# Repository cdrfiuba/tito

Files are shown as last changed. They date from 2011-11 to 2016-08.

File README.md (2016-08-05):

Project created on: 2011-04-29 21:04:24
Project last updated on: 2013-04-11 14:27:10
Project members:
 Martín Mello Teggia <martinmt139@gmail.com>
 Damián Cudero <misael.k@gmail.com>
 anonimo anonimo <nin@guno.com>
 Gisela Farace <gisela.farace@gmail.com>
 Gustavo Crescentini <guscres@gmail.com>

TITO el autito más bonito.

[Descargar copia del repositorio](https://labi.fi.uba.ar/codigo/tito/archive/tip.zip)

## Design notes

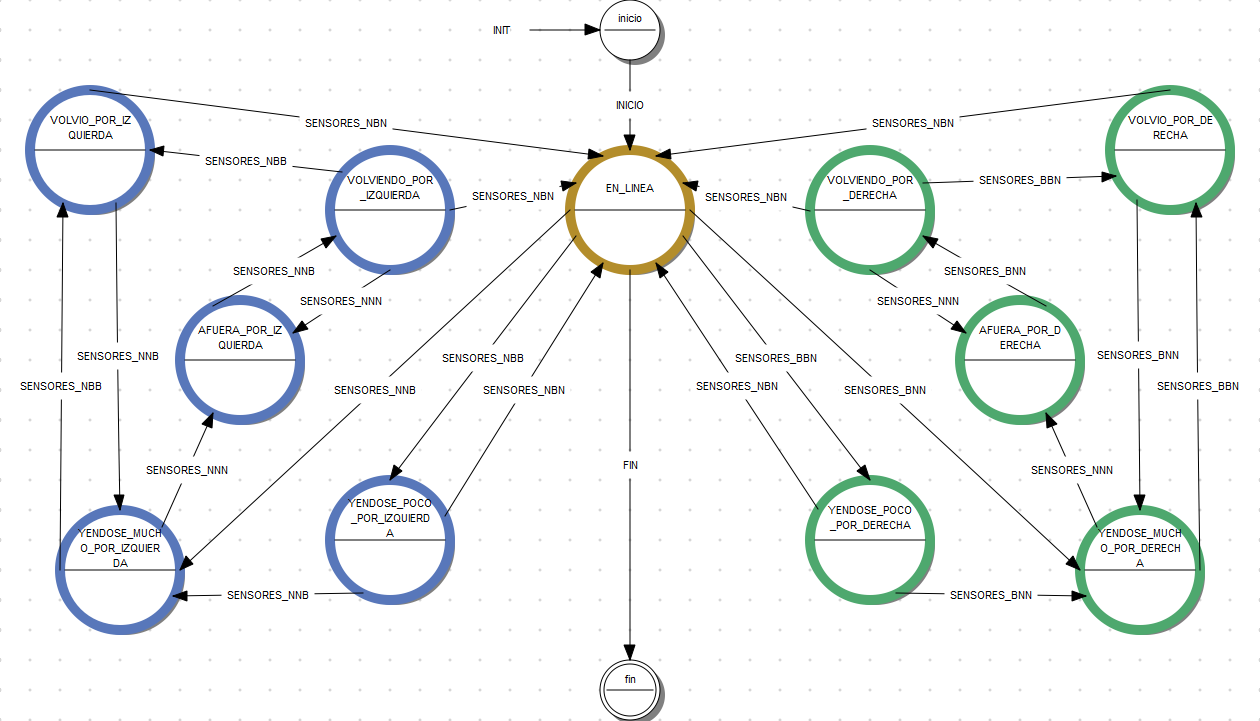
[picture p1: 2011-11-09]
Otros/Maquina de estados.png

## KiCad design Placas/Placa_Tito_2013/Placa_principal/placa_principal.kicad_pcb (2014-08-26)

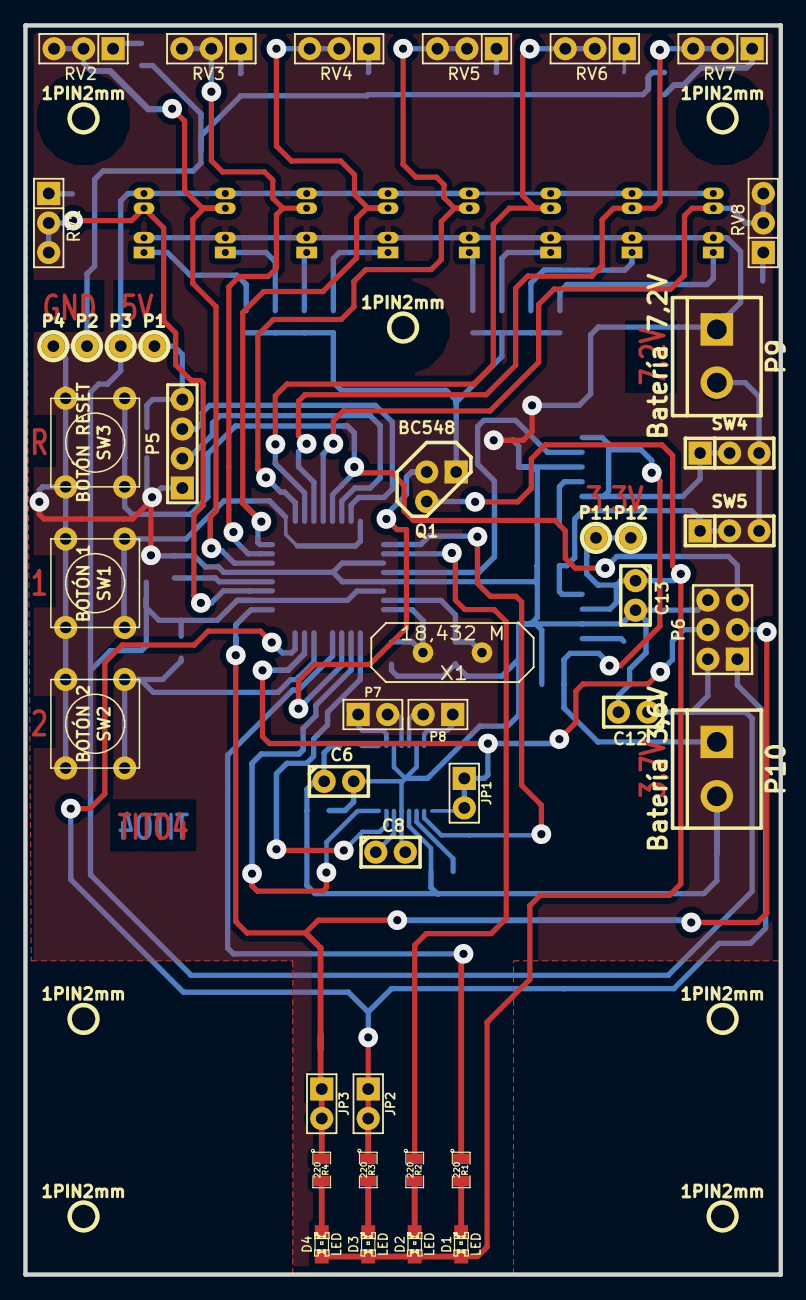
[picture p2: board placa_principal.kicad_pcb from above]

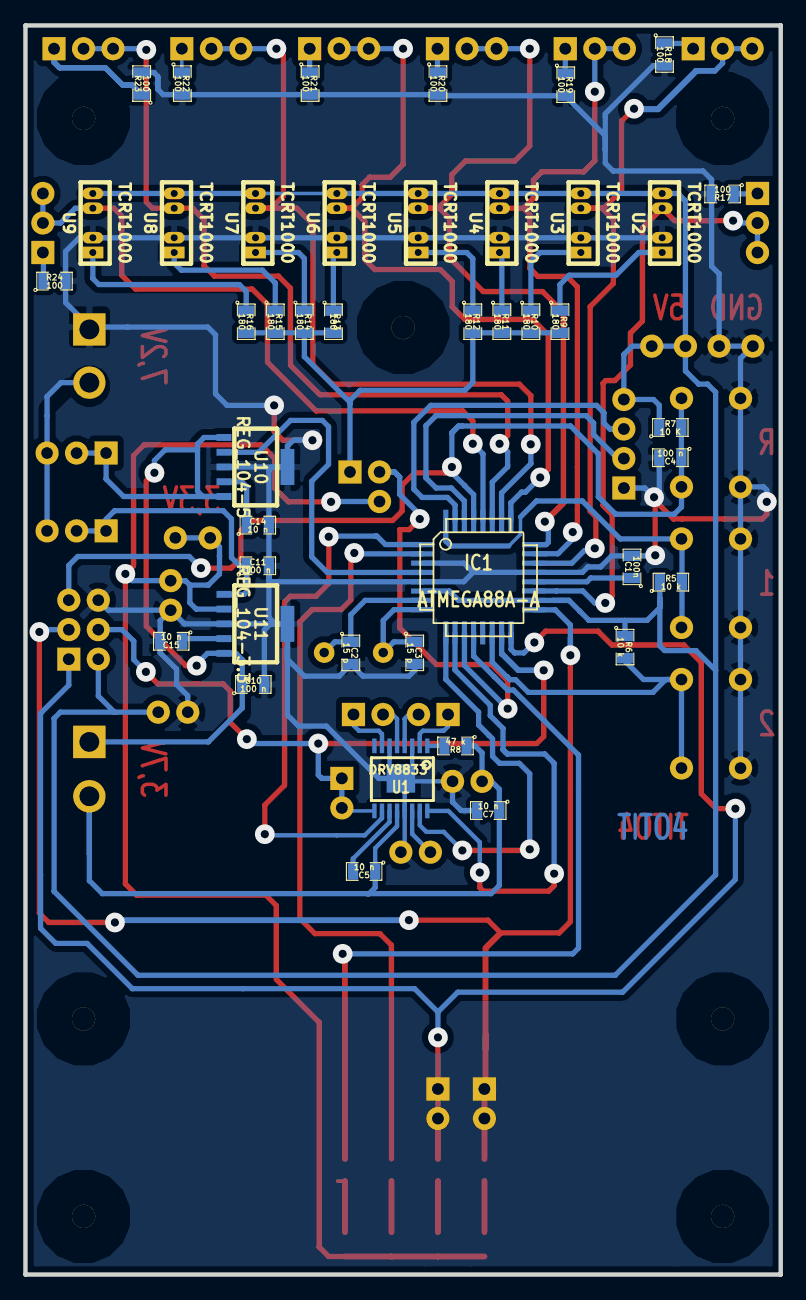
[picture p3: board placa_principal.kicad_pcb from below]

Board: 2 copper layers, 65.0 x 107.5 mm, 91 parts (42 on the bottom side), 65 nets.

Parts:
1PIN2mm, 1PIN2mm#2, 1PIN2mm#3, 1PIN2mm#4, 1PIN2mm#5, 1PIN2mm#6, 1PIN2mm#7: P***; 1PIN2mm
C1: 100n; SM0805
C2, C3: 15 p; SM0805
C4, C10, C11: 100 n; SM0805
C5, C7, C14, C15: 10 n; SM0805
C6: 2200 u; C1
C8: 2,2 u; C1
C12, C13: 220 u; C1
D1, D2, D3, D4: LED; LED-0805
IC1: ATMEGA88A-A; TQFP32
JP1, JP2, JP3: PUENTE FALLBACK; PIN_ARRAY_2X1
P1, P3: ADICIONAL 5V; 1PIN2mm
P2, P4: ADICIONAL GND; 1PIN2mm
P5: Puerto Serie; PIN_ARRAY_4x1
P6: Programador; pin_array_3x2
P7: Motor 1; PIN_ARRAY_2X1
P8: Motor 2; PIN_ARRAY_2X1
P9: Batería 7,2V; bornier2
P10: Batería 3,6V; bornier2
P11, P12: ADICIONAL 3,3V; 1PIN2mm
Q1: BC548; TO92-123
R1, R2, R3, R4: 220; SM0805
R5, R6: 10 k; SM0805
R7: 10 K; SM0805
R8: 47 k; SM0805
R9, R10, R11, R12, R13, R14, R15, R16: 180; SM0805
R17, R18, R19, R20, R21, R22, R23, R24: 100; SM0805
RV1, RV2, RV3, RV4, RV5, RV6, RV7, RV8: POT 20 k; PIN_ARRAY_3X1
SW1: BOTÓN 1; SW_PUSH_SMALL
SW2: BOTÓN 2; SW_PUSH_SMALL
SW3: BOTÓN RESET; SW_PUSH_SMALL
SW4: INTERRUPTOR BATERÍA 7,2V; MICROSWITCH_SPST
SW5: INTERRUPTOR REGULADOR 3,3V; MICROSWITCH_SPST
U1: DRV8833; HTSSOP16
U2, U3, U4, U5, U6, U7, U8, U9: TCRT1000
U10: REG_104-5; SOT223-5
U11: REG_104-3.3; SOT223-5
X1: 18,432 M; HC-18UV

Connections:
+3.3V: C13.1, D1.1, D2.1, D3.1, D4.1, P11.1, P12.1, Q1.1, U11.2
+5V: C12.1, IC1.4, IC1.6, IC1.18, P1.1, P3.1, P5.4, P6.2, R5.1, R6.1, R7.1, U2.4, U3.4, U4.4, U5.4, U6.4, U7.4, U8.4, U9.4, U10.2
+BATT: C5.1, C6.1, C7.1, P10.2, R8.1, U1.12
/BOTÓN 1: IC1.32, R5.2, SW1.1
/BOTÓN 2: IC1.14, R6.2, SW2.1
/Control Motores/MOTOR A SALIDA 1: P7.1, U1.2
/Control Motores/MOTOR A SALIDA 2: P7.2, U1.4
/Control Motores/MOTOR B SALIDA 1: P8.1, U1.7
/Control Motores/MOTOR B SALIDA 2: P8.2, U1.5
/Control Motores/Motor A Entrada 1: IC1.10, U1.16
/Control Motores/Motor A Entrada 2: IC1.9, U1.15
/Control Motores/Motor B Entrada 1: JP1.2, U1.9
/Control Motores/Motor B Entrada 2: IC1.1, U1.10
/LED1: IC1.12, R1.1
/LED2: IC1.2, R2.1
/LED3: JP2.2, R3.1
/LED4: JP3.2, R4.1
/MISO: IC1.16, JP2.1, P6.1
/MOSI: IC1.15, JP1.1, P6.4
/PIN HABILITADOR: IC1.11, Q1.2
/RESET: C4.1, IC1.29, P6.5, R7.2, SW3.1
/RX: IC1.30, P5.2
/SCK: IC1.17, JP3.1, P6.3
/Sensores/Habilitador sensores: Q1.3, R9.2, R10.2, R11.2, R12.2, R13.2, R14.2, R15.2, R16.2
/Sensores/Sensor 1: IC1.19, RV1.2, RV1.3, U2.3
/Sensores/Sensor 2: IC1.22, RV2.2, RV2.3, U3.3
/Sensores/Sensor 3: IC1.23, RV3.2, RV3.3, U4.3
/Sensores/Sensor 4: IC1.24, RV4.2, RV4.3, U5.3
/Sensores/Sensor 5: IC1.25, RV5.2, RV5.3, U6.3
/Sensores/Sensor 6: IC1.26, RV6.2, RV6.3, U7.3
/Sensores/Sensor 7: IC1.27, RV7.2, RV7.3, U8.3
/Sensores/Sensor 8: IC1.28, RV8.2, RV8.3, U9.3
/TX: IC1.31, P5.3
/Xtal1: C2.1, IC1.7, X1.1
/Xtal2: C3.1, IC1.8, X1.2
GND: C1.2, C2.2, C3.2, C4.2, C6.2, C7.2, C8.2, C10.2, C11.2, C12.2, C13.2, C14.2, C15.2, IC1.3, IC1.5, IC1.21, P2.1, P4.1, P5.1, P6.6, P9.1, R17.2, R18.2, R19.2, R20.2, R21.2, R22.2, R23.2, R24.2, SW1.2, SW2.2, SW3.2, U1.3, U1.6, U1.13, U2.2, U3.2, U4.2, U5.2, U6.2, U7.2, U8.2, U9.2, U10.3, U11.3
unnamed: C1.1, IC1.20
unnamed: D3.2, R3.2
unnamed: D4.2, R4.2
unnamed: D1.2, R1.2
unnamed: D2.2, R2.2
unnamed: C11.1, SW5.1, SW5.2, U11.1
unnamed: C10.1, P10.1, SW4.1, SW4.2, U10.1, U10.5, U11.5
unnamed: C14.1, U10.4
unnamed: C15.1, U11.4
unnamed: R8.2, U1.1
unnamed: C5.2, U1.11
unnamed: C8.1, U1.14
unnamed: R14.1, U7.1
unnamed: R13.1, U6.1
unnamed: R15.1, U8.1
unnamed: R11.1, U4.1
unnamed: R22.1, RV6.1
unnamed: R17.1, RV1.1
unnamed: R18.1, RV2.1
unnamed: R19.1, RV3.1
unnamed: R10.1, U3.1
unnamed: R9.1, U2.1
unnamed: R21.1, RV5.1
unnamed: R24.1, RV8.1
unnamed: R23.1, RV7.1
unnamed: R16.1, U9.1
unnamed: R12.1, U5.1
unnamed: R20.1, RV4.1
VDD: P9.2, SW4.3, SW5.3

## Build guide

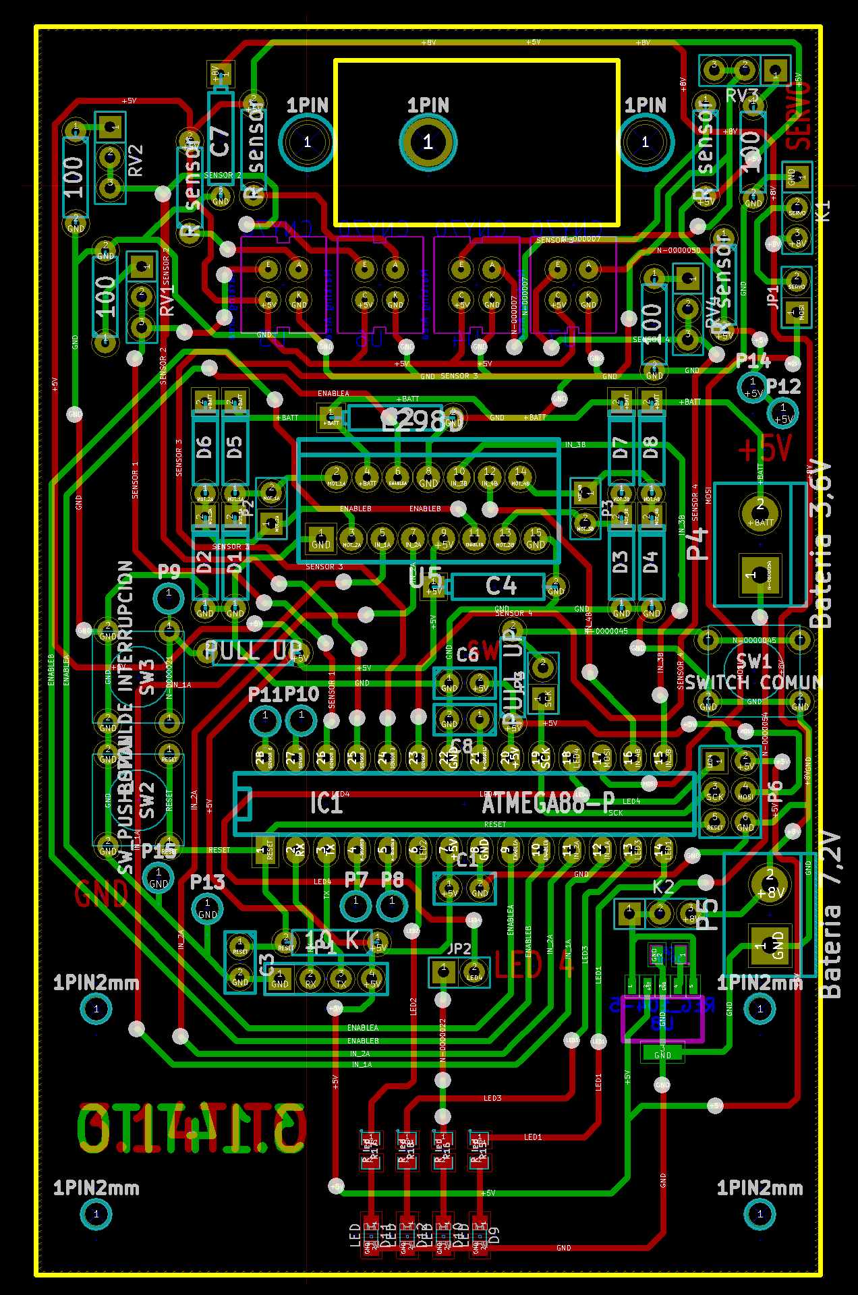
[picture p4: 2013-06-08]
Placas/Placa_Tito_2013/Placa_principal/Archivos de fabricacion/2013/Pantallazo.png

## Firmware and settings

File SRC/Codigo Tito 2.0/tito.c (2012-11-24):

#include <avr/io.h>
#include <avr/interrupt.h>
#define F_CPU 8000000UL
#include <util/delay.h>
#include "tito.h"
#include "lib/lib_pwm.h"
#include <avr/pgmspace.h>

void (*funciones[ST_MAX_ESTADOS])();

volatile uint16_t boost_en_linea_contador;
volatile int boost_en_linea;

void startup () {
// setear puertos de lectura o escritura,
// según corresponda

    // leds
    SetBit (DDR_LED_1, LED_1_NUMBER);
    SetBit (DDR_LED_2, LED_2_NUMBER);
    SetBit (DDR_LED_3, LED_3_NUMBER);
    SetBit (DDR_LED_4, LED_4_NUMBER);

    // sensores
    ClearBit (DDR_SENSOR_1, SENSOR_1_NUMBER);
    ClearBit (DDR_SENSOR_2, SENSOR_2_NUMBER);
    ClearBit (DDR_SENSOR_3, SENSOR_3_NUMBER);
    ClearBit (DDR_SENSOR_CURVA, SENSOR_CURVA_NUMBER);

    // botón
    ClearBit (DDR_BOTON, BOTON_NUMBER);
    SetBit (PORT_BOTON, BOTON_NUMBER);


    // PWM
    pwm_config();
    pwm_start();

    // pone el flag global para activar interrupciones
    sei();

    // establezco la dirección de los motores
    mot1_sent(AD);
    mot2_sent(AD);

}

/*Tabla de Posibles transiciones*/
static const int transiciones[ST_MAX_ESTADOS][EV_MAX_SENSORES] PROGMEM = {
                              /*NNNN NNNB NNBN NNBB NBNN NBNB NBBN NBBB BNNN BNNB BNBN BNBB BBNN BBNB BBBN BBBB*/
/* En Linea*/                   { ME,YMPI,YPPI,YMPI,YPPD,  ME,  ME,  ME,YMPD,  ME,  ME,  ME,YMPD,  ME,  ME,  ME}, 

/* Yendose Poco por Derecha*/   {APD,  ME,  EL,  ME,  ME,  ME,  EL,  ME,YMPD,  ME,  ME,  ME,YMPD,  ME,  ME,  ME}, 
/* Yendose Mucho por Derecha*/  {APD,VOPD,VOPD,VOPD,  EL,  ME,VOPD,  ME,  ME,  ME,  ME,  ME,  ME,  ME,  ME,  ME},
/* Afuera por Derecha*/         { ME,  ME,  ME,  ME,  ME,  ME,  ME,  ME,VEPD,  ME,  ME,  ME,VEPD,  ME,  ME,  ME}, 
/* Volviendo por Derecha*/      {APD,  ME,VOPD,  ME,  EL,  ME,  EL,  ME,  ME,  ME,  ME,  ME,  ME,  ME,  ME,  ME}, 
/* Volvio por Derecha*/         { ME,  ME,  EL,  ME,  EL,  ME,  EL,  ME,  ME,  ME,  ME,  ME,YPPD,  ME,  ME,  ME}, 

/* Yendose Poco por Izquierda*/ {API,YMPI,  ME,YMPI,  EL,  ME,  EL,  ME,  ME,  ME,  ME,  ME,  ME,  ME,  ME,  ME},
/* Yendose Mucho por Izquierda*/{API,  ME,  EL,  ME,VOPI,  ME,VOPI,  ME,VOPI,  ME,  ME,  ME,VOPI,  ME,  ME,  ME}, 
/* Afuera por Izquierda*/       { ME,VEPI,  ME,VEPI,  ME,  ME,  ME,  ME,  ME,  ME,  ME,  ME,  ME,  ME,  ME,  ME}, 
/* Volviendo por Izquierda*/    {API,  ME,  EL,  ME,VOPI,  ME,  EL,  ME,  ME,  ME,  ME,  ME,  ME,  ME,  ME,  ME}, 
/* Volvio por Izquierda*/       { ME,  ME,  EL,YPPI,  EL,  ME,  EL,  ME,  ME,  ME,  ME,  ME,  ME,  ME,  ME,  ME}  
};


void st_en_linea () {
    PWM1_VEL(COEFICIENTE_IZQUIERDA * (60 + 0));
    PWM2_VEL(COEFICIENTE_DERECHA   * (60 + 0));
    mot1_sent(AD);
    mot2_sent(AD);
};

void st_yendose_poco_por_derecha () {
	//USAR_FRENOS(250, 250);
    #ifdef ACTIVAR_PROPULSORES_TRASEROS
        PWM1_VEL(1.4 * COEFICIENTE_IZQUIERDA * 100);
        PWM2_VEL(1.4 * COEFICIENTE_DERECHA  *  50);
        mot1_sent(AD);
        mot2_sent(AT);
        _delay_ms (1);
    #endif
          
    PWM1_VEL(COEFICIENTE_IZQUIERDA * 100 * 1.8);
    PWM2_VEL(COEFICIENTE_DERECHA  *   90 * 1.8);
    mot1_sent(AD);
    mot2_sent(AD);
};
void st_yendose_mucho_por_derecha () {
	USAR_FRENOS(250, 2000);
    #ifdef ACTIVAR_PROPULSORES_TRASEROS
        PWM1_VEL(COEFICIENTE_IZQUIERDA * 40);
        PWM2_VEL(COEFICIENTE_DERECHA *   100);
        mot1_sent(AT);
        mot2_sent(AD);
        _delay_ms (2);
        PWM1_VEL(COEFICIENTE_IZQUIERDA *  70);
        PWM2_VEL(COEFICIENTE_DERECHA *   100);
        mot1_sent(AT);
        mot2_sent(AD);
        _delay_ms (2);
        PWM1_VEL(COEFICIENTE_IZQUIERDA * 100);
        PWM2_VEL(COEFICIENTE_DERECHA *   100);
        mot1_sent(AT);
        mot2_sent(AD);
        _delay_ms (2);
    #endif

    PWM1_VEL(COEFICIENTE_IZQUIERDA *  10);
    PWM2_VEL(COEFICIENTE_DERECHA *   100);
    mot1_sent(AT);
    mot2_sent(AD);
};
void st_afuera_por_derecha () {
	USAR_FRENOS(250, 2000);
    #ifdef ACTIVAR_PROPULSORES_TRASEROS
        PWM1_VEL(COEFICIENTE_IZQUIERDA *  90);
        PWM2_VEL(COEFICIENTE_DERECHA  *  100);
        mot1_sent(AT);
        mot2_sent(AD);
        _delay_ms (10);
    #endif

    PWM1_VEL(COEFICIENTE_IZQUIERDA *  45);
    PWM2_VEL(COEFICIENTE_DERECHA  *  100);
    mot1_sent(AT);
    mot2_sent(AD);
};
void st_volviendo_por_derecha () {
	USAR_FRENOS(250, 500);
/*    #ifdef ACTIVAR_PROPULSORES_TRASEROS
        PWM1_VEL(COEFICIENTE_IZQUIERDA *  100);
        PWM2_VEL(COEFICIENTE_DERECHA   * 100);
        mot1_sent(AD);
        mot2_sent(AD);
        _delay_ms (10);
    #endif
*/    

    PWM1_VEL(COEFICIENTE_IZQUIERDA *  50);
    PWM2_VEL(COEFICIENTE_DERECHA   * 100);
    mot1_sent(AD);
    mot2_sent(AD);
};
void st_volvio_por_derecha () {
	//USAR_FRENOS(500, 500);
    #ifdef ACTIVAR_PROPULSORES_TRASEROS
        PWM1_VEL(COEFICIENTE_IZQUIERDA * 100);
        PWM2_VEL(COEFICIENTE_DERECHA   *  100);
        mot1_sent(AD);
        mot2_sent(AT);
        _delay_ms (10);
    #endif
    
    PWM1_VEL(COEFICIENTE_IZQUIERDA * 100);
    PWM2_VEL(COEFICIENTE_DERECHA   *  85);
    mot1_sent(AD);
    mot2_sent(AD);
};

void st_yendose_poco_por_izquierda () {
	//USAR_FRENOS(250, 250);
    #ifdef ACTIVAR_PROPULSORES_TRASEROS
        PWM1_VEL(1.4 * COEFICIENTE_IZQUIERDA *  50);
        PWM2_VEL(1.4 * COEFICIENTE_DERECHA   * 100);
        mot1_sent(AT);
        mot2_sent(AD);
        _delay_ms (1);
    #endif
    
    PWM1_VEL(COEFICIENTE_IZQUIERDA *  90 * 1.8);
    PWM2_VEL(COEFICIENTE_DERECHA   * 100 * 1.8);
    mot1_sent(AD);
    mot2_sent(AD);
};
void st_yendose_mucho_por_izquierda () {
	USAR_FRENOS(250, 2000);
    #ifdef ACTIVAR_PROPULSORES_TRASEROS
        PWM1_VEL(COEFICIENTE_IZQUIERDA * 100);
        PWM2_VEL(COEFICIENTE_DERECHA   *  40);
        mot1_sent(AD);
        mot2_sent(AT);
        _delay_ms (2);    
        PWM1_VEL(COEFICIENTE_IZQUIERDA * 100);
        PWM2_VEL(COEFICIENTE_DERECHA   *  70);
        mot1_sent(AD);
        mot2_sent(AT);
        _delay_ms (2);    
        PWM1_VEL(COEFICIENTE_IZQUIERDA * 100);
        PWM2_VEL(COEFICIENTE_DERECHA   * 100);
        mot1_sent(AD);
        mot2_sent(AT);
        _delay_ms (2);    
    #endif
    
    PWM1_VEL(COEFICIENTE_IZQUIERDA * 100);
    PWM2_VEL(COEFICIENTE_DERECHA   *  10);
    mot1_sent(AD);
    mot2_sent(AT);
};
void st_afuera_por_izquierda () {
	USAR_FRENOS(250, 2000);
    #ifdef ACTIVAR_PROPULSORES_TRASEROS
        PWM1_VEL(COEFICIENTE_IZQUIERDA * 100);
        PWM2_VEL(COEFICIENTE_DERECHA   *  90);
        mot1_sent(AD);
        mot2_sent(AT);
        _delay_ms (10);
    #endif
    
    PWM1_VEL(COEFICIENTE_IZQUIERDA * 100);
    PWM2_VEL(COEFICIENTE_DERECHA   *  45);
    mot1_sent(AD);
    mot2_sent(AT);
};
void st_volviendo_por_izquierda () {
	USAR_FRENOS(250, 500);
/*    #ifdef ACTIVAR_PROPULSORES_TRASEROS
        PWM1_VEL(COEFICIENTE_IZQUIERDA * 100);
        PWM2_VEL(COEFICIENTE_DERECHA   *  100);
        mot1_sent(AD);
        mot2_sent(AT);
        _delay_ms (10);    
    #endif
*/    

    PWM1_VEL(COEFICIENTE_IZQUIERDA * 100);
    PWM2_VEL(COEFICIENTE_DERECHA   *  50);
    mot1_sent(AD);
    mot2_sent(AD);
};
void st_volvio_por_izquierda () {
	//USAR_FRENOS(500, 500);
    #ifdef ACTIVAR_PROPULSORES_TRASEROS
        PWM1_VEL(COEFICIENTE_IZQUIERDA *  100);
        PWM2_VEL(COEFICIENTE_DERECHA   * 100);
        mot1_sent(AT);
        mot2_sent(AD);
        _delay_ms (10);
    #endif

    PWM1_VEL(COEFICIENTE_IZQUIERDA *  80);
    PWM2_VEL(COEFICIENTE_DERECHA   * 100);
    mot1_sent(AD);
    mot2_sent(AD);
};

/**
 función principal
*/
int main() {
    int estado_actual;
    int nuevo_estado;
    int estado_sensores;
    int estado_sensores_nuevo;
    
    startup();
    
    funciones[ST_EN_LINEA] = st_en_linea;
    
    funciones[ST_YENDOSE_POCO_POR_DERECHA] = st_yendose_poco_por_derecha;
    funciones[ST_YENDOSE_MUCHO_POR_DERECHA] = st_yendose_mucho_por_derecha;
    funciones[ST_AFUERA_POR_DERECHA] = st_afuera_por_derecha;
    funciones[ST_VOLVIENDO_POR_DERECHA] = st_volviendo_por_derecha;
    funciones[ST_VOLVIO_POR_DERECHA] = st_volvio_por_derecha;

    funciones[ST_YENDOSE_POCO_POR_IZQUIERDA] = st_yendose_poco_por_izquierda;
    funciones[ST_YENDOSE_MUCHO_POR_IZQUIERDA] = st_yendose_mucho_por_izquierda;
    funciones[ST_AFUERA_POR_IZQUIERDA] = st_afuera_por_izquierda;
    funciones[ST_VOLVIENDO_POR_IZQUIERDA] = st_volviendo_por_izquierda;
    funciones[ST_VOLVIO_POR_IZQUIERDA] = st_volvio_por_izquierda;
    
    
    while (1){
        PWM1_VEL(0);
        PWM2_VEL(0);
        boost_en_linea_contador = 0;

        // ciclos para esperar a que arranque cuando
        // se suelta el botón
        while (BOTON_NO_APRETADO);
        _delay_ms(50); //rebote botón
        

        while (BOTON_APRETADO);
        _delay_ms(5); //rebote botón

        // aceleración inicial gradual
        PWM1_VEL(50);
        PWM2_VEL(50);
        _delay_ms(50);
        
        // inicialización estado
        estado_actual = ST_EN_LINEA;
        nuevo_estado = ST_EN_LINEA;
        (*funciones[estado_actual])();
        
        while (BOTON_NO_APRETADO) {
        
            estado_sensores = ESTADO_SENSORES;
            while(1) {
                estado_sensores_nuevo = ESTADO_SENSORES; // obtiene el evento a procesar
                if (estado_sensores_nuevo == estado_sensores) {
                    break;
                }
                estado_sensores = estado_sensores_nuevo;
            }

            // boost "integrativo" para el estado en línea
            /*if (estado_actual == ST_EN_LINEA) {
                boost_en_linea_contador += 1;
                if ((boost_en_linea = (boost_en_linea_contador >> 4)) > 50) {
                    boost_en_linea = 50;
                }
                (*funciones[estado_actual])();
            } else {
                boost_en_linea_contador = 0;
            }*/
            
            if ((nuevo_estado = pgm_read_byte_near(&(transiciones[estado_actual][estado_sensores]))) != ST_MAX_ESTADOS) {
                estado_actual = nuevo_estado;
                (*funciones[estado_actual])();
            }
        }

        // fin de tareas, para poder empezar de nuevo
        PWM1_VEL(0);
        PWM2_VEL(0);
        _delay_ms(50); //rebote botón

        while (BOTON_APRETADO);
        _delay_ms(50); //rebote botón
        
    }
}


/*void prueba_frenado(void){
    while(1)
    {   
        estado_sensores = ESTADO_SENSORES;
        if(estado_sensores)
        {   PWM1_VEL(COEFICIENTE_IZQUIERDA * 0);
            PWM2_VEL(COEFICIENTE_DERECHA   * 0);
            mot1_sent(AD);
            mot2_sent(AD);
        }
        else
        {   PWM1_VEL(COEFICIENTE_IZQUIERDA * 100);
            PWM2_VEL(COEFICIENTE_DERECHA   * 100);
            mot1_sent(AD);
            mot2_sent(AD);
        } 
    }
}*/

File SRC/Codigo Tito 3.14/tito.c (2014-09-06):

//#define F_CPU 1000000UL
#include <avr/io.h>
#include <avr/interrupt.h>
#include <util/delay.h>
#include "tito.h"
#include "lib/motores.h"
#include "lib/common.h"
#include "lib/usart.c"
#include <stdio.h>

volatile uint8_t tolerancia = 30;

int usart_putchar_printf(char var, FILE *stream) {
    if (var == '\n') USART0Transmit('\r');
    USART0Transmit(var);
    return 0;
}

static FILE mystdout = FDEV_SETUP_STREAM(usart_putchar_printf, NULL, _FDEV_SETUP_WRITE);

inline void setear_conversor_ad(uint8_t sensor){
    ADMUX &= ~((1 << MUX3) | (1 << MUX2) | (1 << MUX1) | (1 << MUX0)); 
    ADMUX |= sensor; 
}
void configurar_adc(void) {
    ADMUX = ( (0 << REFS1) | (1 << REFS0) | (1 << ADLAR) | (1 << MUX3) | (1 << MUX2) | (1 << MUX1) | (1 << MUX0) );
    ADCSRA = ( (1 << ADEN) | (0 << ADSC) | (0 << ADATE) | (0 << ADIE)  | (0 << ADPS2) | (0 << ADPS1)| (0 << ADPS0) );
    ADCSRB = ( (0 << ADTS2) | (0 << ADTS1) | (0 << ADTS0) | (0 << ACME) );
}

void startup () {
// setear puertos de lectura o escritura,
// según corresponda

    stdout = &mystdout;

    // leds
    SetBit (DDR_LED_1, LED_1_NUMBER);
    SetBit (DDR_LED_2, LED_2_NUMBER);
    SetBit (DDR_LED_3, LED_3_NUMBER);
    SetBit (DDR_LED_4, LED_4_NUMBER);

    // sensores
    ClearBit (DDR_SENSOR_1, SENSOR_1_NUMBER);
    ClearBit (DDR_SENSOR_2, SENSOR_2_NUMBER);
    ClearBit (DDR_SENSOR_3, SENSOR_3_NUMBER);
    ClearBit (DDR_SENSOR_4, SENSOR_4_NUMBER);
    ClearBit (DDR_SENSOR_5, SENSOR_5_NUMBER);
    ClearBit (DDR_SENSOR_6, SENSOR_6_NUMBER);

    // botón1
    ClearBit (DDR_BOTON1, BOTON1_NUMBER);
    SetBit (PORT_BOTON1, BOTON1_NUMBER);

    // botón2
    ClearBit (DDR_BOTON2, BOTON2_NUMBER);
    SetBit (PORT_BOTON2, BOTON2_NUMBER);

    // configuración de PWMs en motores.h
    pwm_config();
    
    // configura los sensores para usar ADC
    configurar_adc();
    
    // inicialización de puerto serie
    USART0Setup(USART_BAUDRATE, USART0_CHARSIZE_8BIT, USART0_STOP_1BIT, USART0_PARITY_DIS, USART0_MODE_ASYNC);
    _delay_ms(10);

    // uno de los motores usa un timer de 16 bits,
    // pero se usa como si fuera de 8, por lo que la
    // parte alta del registro de 16 bits va en 0
    OCR1AH = 0;
    OCR1BH = 0;

    // pone el flag global para activar interrupciones
    //sei();

}

inline void obtener_sensores(uint8_t *sensores) {
    uint8_t i;
    
    for (i = 0; i < MAX_SENSORES ; i++) {
        setear_conversor_ad (i);
        iniciar_conversion_ad();
        while(CONVIRTIENDO_AD);
        sensores[i] = LEER_CONVERSION_AD;
    }
}


void mostrar_sensor_en_leds (uint8_t sensor) {
    uint8_t sensores[MAX_SENSORES] = MAX_SENSORES_INIT;
    obtener_sensores(sensores);

    if (IsBitSet(sensores[sensor], 7)) {
        SetBit(PORT_LED_1, LED_1_NUMBER);
    } else {
        ClearBit(PORT_LED_1, LED_1_NUMBER);
    }
    if (IsBitSet(sensores[sensor], 6)) {
        SetBit(PORT_LED_2, LED_2_NUMBER);
    } else {
        ClearBit(PORT_LED_2, LED_2_NUMBER);
    }
    if (IsBitSet(sensores[sensor], 5)) {
        SetBit(PORT_LED_3, LED_3_NUMBER);
    } else {
        ClearBit(PORT_LED_3, LED_3_NUMBER);
    }
    if (IsBitSet(sensores[sensor], 4)) {
        SetBit(PORT_LED_4, LED_4_NUMBER);
    } else {
        ClearBit(PORT_LED_4, LED_4_NUMBER);
    }
}

inline void mostrar_leds(uint8_t *sensores) {
    //static uint8_t boton_apretado = 0;

    //while (BOTON1_APRETADO) {
        //boton_apretado = 1;
    //}
    //_delay_ms(5); //rebote botón
    //if (boton_apretado == 1) {
        //tolerancia = tolerancia + 5;
        //if (tolerancia == 180) {
            //tolerancia = 0;
        //}
        //boton_apretado = 0;
    //}

    if (sensores[S6] > tolerancia) {
        SetBit(PORT_LED_1, LED_1_NUMBER);
    } else {
        ClearBit(PORT_LED_1, LED_1_NUMBER);
    }
    if ( (sensores[S5] > tolerancia) && (sensores[S4] > tolerancia) ) {
        SetBit(PORT_LED_2, LED_2_NUMBER);
    } else {
        ClearBit(PORT_LED_2, LED_2_NUMBER);
    }
    if ( (sensores[S3] > tolerancia) && (sensores[S2] > tolerancia) ) {
        SetBit(PORT_LED_3, LED_3_NUMBER);
    } else {
        ClearBit(PORT_LED_3, LED_3_NUMBER);
    }
    if (sensores[S1] > tolerancia) {
        SetBit(PORT_LED_4, LED_4_NUMBER);
    } else {
        ClearBit(PORT_LED_4, LED_4_NUMBER);
    }

    // printf("%3d %3d %3d %3d %3d %3d\n", sensores[S1], sensores[S2], sensores[S3], sensores[S4], sensores[S5], sensores[S6]);

}

    
/**
 función principal
*/
int main() {
    uint8_t sensores[MAX_SENSORES] = MAX_SENSORES_INIT;
    int16_t sensores_linea = 0;
    int16_t err_p = 0;
    int16_t err_p_anterior = 0;
    int16_t err_d = 0;
    int16_t err_i = 0;
    int16_t reduccion_velocidad = 0;
    estados_t estado_actual = ST_EN_PISTA;
    bordes_t ultimo_borde_valido = BORDE_IZQUIERDA;
    //int8_t coeficiente_error_p = 14;
    //int16_t coeficiente_error_i = 12016;
    //int8_t coeficiente_error_d = 6;
    //int8_t tipo_coeficiente = 0; // de 0 a 15
    //int16_t gusty1 = 0;
    //int16_t gusty2 = 0;
    //int16_t gusty3 = 0;
    startup();
        
    while (1) {
        motores_off();
        ClearBit(PORT_LED_1, LED_1_NUMBER);
        ClearBit(PORT_LED_2, LED_2_NUMBER);
        ClearBit(PORT_LED_3, LED_3_NUMBER);
        ClearBit(PORT_LED_4, LED_4_NUMBER);
        
        //// cambios de coeficientes
        //if (tipo_coeficiente == 16) {
            //tipo_coeficiente = 0;
        //}
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

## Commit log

2011-04-30 primer commit realizado, se procede a subir al repo el proyecto con la placa. db = BaseDeDatos.BaseDeDatos() u = db.get_user(user)
    [placa_principal.sch, placa_sensores.brd, placa_sensores.sch]
2011-04-30 Cambios minimos en la placa, se empezo con la generacion de la netlist.
    [placa_principal.sch]
2011-05-07 Cambiamos de regulador a un LDO de más corriente. Cambiamos algunos pines para facilitar el diseño del PCB.
    [placa_principal.sch]
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2011-05-14 Cambios a la placa, routeada pero con muchos cables y faltan algunas vias. Agregado magia de diodos para Puente-H.
    [$savepcb.brd, placa_principal.brd, placa_principal.dsn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]
2011-05-28 nuevo trabajo sobre el pcb, agregamos las especificaciones del regulador de tension, falta cambiar el encapsulado del mismo, agregar smd.
    [$savepcb.brd, placa_principal.brd, placa_principal.dsn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]
2011-06-04 agrego regulador de tension, y TERMINAMOS EL PCB!!!
    [$savepcb.brd, placa_principal.brd, placa_principal.sch]
2011-06-08 Corregido problema de conectividad en la placa entre las tierras, y agregado un plano de masa (bajo el regulador de tension)
    [$savepcb.brd, placa_principal.brd]
2011-06-15 reestructure el pcb, y agregue el boton. ahora esta linda la placa
    [$savepcb.brd, placa_principal.brd, placa_principal.sch]
2011-06-16 borre algunas pistas que estaban duplicadas, agrego el tito.h con algunas definiciones para ir construyendo en base a eso.
    [$savepcb.brd, placa_principal.brd]
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2011-09-10 subi .lib y .mod cny70 + algo te placa sensores
    [placa_sensores.sch]
2011-11-01 Agrego la placa para un solo sensor
    [$savepcb.brd, placa1sensor.brd, placa1sensor.sch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]
2011-11-02 Placa para un sensor terminada, ANDA!. Ya anda la parte electronica completa, y se esta empezando con el codigo basico.
    [$savepcb.brd, placa1sensor.brd, placa1sensor.sch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]
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2012-02-25 Separamos la placa de tito en 2, una carpeta que contiene lo hecho hasta ahora, y otra placa que tiene lo que va a ser el nuevo pcb de tito, todavia por hacer. Tambien agregamos los .lib y .mod que v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
    [$savepcb.brd, placa1sensor.brd, placa1sensor.sch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]
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2012-10-23 Ahora andan los estados con el pwm y el pwm negado, pero no es posible hacer andar el codigo anterior con este método, hay un bug en algun lugar!
    [tito.c]
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2012-11-17 Arrancamos la placa nueva
    [placa_principal.sch]
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2012-12-15 Terminamos el diseño del esquematico de la nueva placa, falta asociar componentes
    [placa_principal.sch]
2012-12-22 Algunos cambios en la alimentacion del servo, y asociacion de los primeros componentes
    [placa_principal.sch]
2013-02-23 Agregamos placa 2013, con el esquematico completo
    [$savepcb.brd, placa_principal.brd, placa_principal.dsn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]
2013-03-09 Liberadas interrupciones del micro para usar con futuros encoders, emprolijado esquematico
    [placa_principal.sch]
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2013-04-13 Se terminaron de acomodar los componentes en la placa, y se inició el routeo de la misma
    [placa_principal.kicad_pcb, placa_principal.sch]
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2013-04-20 Casi finalizamos de routear la placa
    [placa_principal.kicad_pcb, placa_principal.sch]
2013-04-27 Terminado el ruteo! Incluidos los Gerber, drill, y Daiquiris de Frutilla
    [placa_principal.kicad_pcb, placa_principal.sch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]
2013-05-04 Agrego una seccion para el codigo del nuevo autito, y mapeo todos los pines.
    [placa_principal.drl]
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2013-05-04 Acomodo los archivos en el repo de tito
    [$savepcb.brd, placa1sensor.brd, placa1sensor.sch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]
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2013-05-04 Acomodo mas el repo 3
    [$savepcb.brd, placa1sensor.brd, placa1sensor.sch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]
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2013-06-01 Mejoras a placa principal
    [placa_principal.kicad_pcb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]
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2013-06-08 Borrados archivos innecesarios e ignorados. Corregidas rutas lib en Kicad.
    [$savepcb.brd, placa_principal.brd, placa_principal.dsn]
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2013-07-12 Agrego las bibliotecas del tcrt1000, y cambio los componentes en el esquemático
    [placa_principal.sch]
2013-07-13 Se termino de routear la placa con los nuevos sensores
    [placa_principal.kicad_pcb, placa_principal.sch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]
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2014-02-15 Agrego hoja de datos del BC548C, y realizo cambios propuestos sobre el esquematico de la placa
    [placa_principal.sch]
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2014-03-07 Empezados conversores 5V a 3,3V y viceversa en esquemático.
    [placa_principal.sch]
2014-05-12 Creo y agrego el esquematico de nuestro nuevo puente H (DRV8833), falta corregir ruta de la biblioteca
    [placa_principal.sch]
2014-05-17 Empezados cambios en esquemático para puente H SMD, DRV8833. Agregado datasheet del mismo al repo.
    [placa_principal.sch]
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2014-06-05 Separadas partes del esquématico en varias hojas. Ajustes al esquemático.
    [Alimentacion.sch, Control_motores.sch, Sensores.sch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]
2014-06-12 Ajustes de estandarización de nombres en componentes y etiquetas del esquemático. Removido cny70 del .pro, agregado datasheet tcrt1000
    [Alimentacion.sch, Control_motores.sch, Sensores.sch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]
2014-06-14 Terminado esquemático. Comenzado a asociar componentes.
    [Alimentacion.sch, Control_motores.sch, Sensores.sch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]
2014-07-04 Asociado componente que faltaba, reseteados componentes de la placa.
    [placa_principal.kicad_pcb]
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2014-07-07 Preparado para hacer un tcrt1000 de patas dobladas
    [placa_principal.kicad_pcb]
2014-07-19 Colocados 8 sensores en la placa.
    [Alimentacion.sch, Control_motores.sch, Sensores.sch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]
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2014-08-20 Terminamos de posicionar componentes, y comenzamos el routeo
    [Alimentacion.sch, Control_motores.sch, Sensores.sch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]
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
